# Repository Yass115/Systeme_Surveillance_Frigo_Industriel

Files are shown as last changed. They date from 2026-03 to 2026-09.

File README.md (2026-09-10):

# Système de surveillance d'un frigo industriel

Projet réalisé dans le cadre du cours **Conception et analyse de schémas** — ISIB, cours de M. Rodrigues.

## Objectif du projet

Concevoir une électronique de mesure et de surveillance destinée à être embarquée dans un frigo industriel, capable de détecter et signaler tout comportement anormal (porte oubliée, dérive de température, coupure de courant), depuis le schéma électronique jusqu'au circuit imprimé fini.

## Cahier des charges

| Exigence | Détail |
|---|---|
| Environnement | Boîtier étanche, tenue aux températures négatives |
| Mesure de température | Thermocouples, de préférence type T, connecteurs standards |
| Résolution | 1 °C ou mieux |
| Alerte à distance | En cas de comportement anormal (porte ouverte, baisse anormale de température, …) |
| Alerte locale | Alarme sonore/visuelle sur place |
| Communication | Ethernet |
| Consommation | Minimale |
| Alimentation | Protection contre les coupures de courant (secours sur batterie) |
| Indication | Témoins de fonctionnement (LEDs d'état) |

## Structure du projet

Le cours se déroule en deux volets complémentaires, correspondant aux deux dossiers du dépôt :

### 1. Schématique — `schematic/`
- Analyse du cahier des charges et découpage fonctionnel du système
- Choix et justification des composants (datasheets, calculs de dimensionnement)
- Câblage du schéma électronique complet
- Vérification des règles électriques (ERC)

### 2. Circuit imprimé — `pcb/`
- Placement des composants et contraintes mécaniques (boîtier, connecteurs)
- Routage des pistes (KiCad)
- Respect des règles de conception (largeur de piste, isolation, plan de masse)
- Génération des fichiers de fabrication (Gerbers, BOM, plan de perçage)

## Architecture électronique retenue

| Bloc | Composant | Rôle |
|---|---|---|
| Microcontrôleur | STM32L476 | Traitement, logique de surveillance |
| Mesure température (thermocouple) | MAX31855 + thermocouple type T | Mesure haute précision |
| Mesure température (secours/locale) | DS18B20 | Redondance de mesure |
| Communication | W5500 + MagJack RJ45 | Interface Ethernet |
| Alimentation secteur | HLK-PM01 (230 V → 5 V) | Alimentation principale isolée |
| Régulation | AMS1117-3.3 | Alimentation logique 3,3 V |
| Secours | Pile CR123A | Continuité de service en cas de coupure |

> La zone réseau 230 V est isolée de la basse tension par une barrière d'isolement, conformément aux règles de sécurité électrique.

## Outils utilisés

- **KiCad** — schématique et routage PCB
- **LaTeX** — rédaction du rapport de conception

## Organisation des fichiers

```
├── schematic/          # Fichiers de schéma KiCad, notes de choix de composants
├── pcb/                # Layout, règles de conception, fichiers de fabrication
├── datasheets/         # Documentation des composants clés
├── rapport/            # Rapport LaTeX du projet
└── README.md
```

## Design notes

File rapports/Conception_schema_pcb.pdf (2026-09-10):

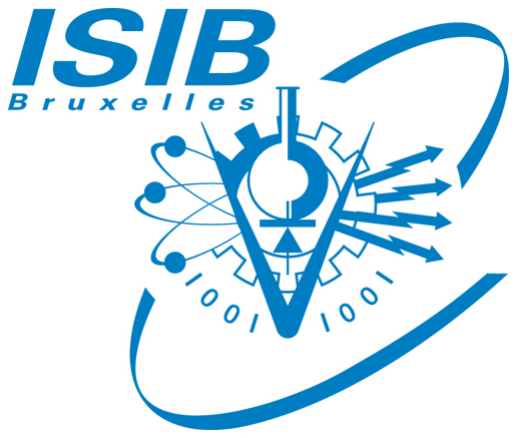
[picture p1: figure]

Institut Supérieur Industriel de Bruxelles

# Conception du circuit imprimé

## Système de surveillance d’un frigo industriel

Auteur : Yassine AMINE EL JAZAR

Professeur : M. Abilio Sergio RODRIGUES E SOUSA

Date : 2 septembre 2026

Rue des Goujons 28, 1070 Bruxelles (Belgique)

Conception du circuit imprimé

## Table des matières

1 Introduction | 1
2 Architecture à intégrer sur le PCB | 1
3 Contraintes de conception | 2
4 Technologie du circuit imprimé | 2
5 Zonage et placement des composants | 2
6 Isolement de la partie secteur | 5
7 Dimensionnement des pistes | 6
8 Routage des fonctions sensibles | 7
9 Étude thermique | 9
10 Règles mécaniques et assemblage | 9
11 Conclusion | 13
Références | 14

i

## 1 Introduction

Ce rapport est consacré à la conception du circuit imprimé du système de surveillance d’un frigo industriel. L’objectif n’est plus de comparer les composants possibles, mais de transformer l’architecture électronique retenue en une carte réalisable, sûre et fiable.
La carte doit mesurer la température au moyen d’un thermocouple de type T et d’un capteur DS18B20, traiter les données avec un microcontrôleur STM32L476, transmettre les informations par Ethernet et déclencher une alarme en cas d’anomalie. Elle doit également être alimentée depuis le secteur et continuer temporairement à fonctionner grâce à une pile de secours.
La conception du PCB doit donc répondre simultanément à plusieurs contraintes : présence du secteur 230 V, signaux de mesure de très faible amplitude, interface Ethernet, alimentation 3,3 V, fonctionnement dans un environnement froid et facilité de fabrication. Les règles présentées dans le document de cours Conception des circuits imprimés servent de base pour définir les largeurs de piste, les espacements, le plan de masse et les précautions thermiques.

## 2 Architecture à intégrer sur le PCB

Le schéma électrique est organisé autour des sous-ensembles présentés dans le tableau 1. Ces éléments constituent les données d’entrée de la conception du circuit imprimé.

Sous-ensemble | Composant principal | Fonction sur la carte
Traitement | STM32L476 | Acquisition des mesures, gestion des alarmes et communication avec les périphériques.
Mesure principale | MAX31855 + thermocouple T | Conversion du faible signal du thermocouple et transmission numérique par SPI.
Mesure ambiante | DS18B20 | Mesure numérique complémentaire par bus 1-Wire.
Communication | W5500 + Mag-Jack RJ45 | Gestion de la pile TCP/IP et liaison Ethernet vers l’extérieur du frigo.
Alimentation sec-teur | HLK-PM01 | Conversion isolée du 230 V alternatif vers 5 V continu.
Régulation | AMS1117-3.3 | Production du rail 3,3 V utilisé par les circuits nu-mériques.
Alimentation de secours | Pile CR123A | Maintien temporaire de la surveillance lors d’une coupure secteur.
Signalisation | LED, buzzer et relais éventuel | Indication de l’état du système et déclenchement d’une alarme locale.

Table 1 – Sous-ensembles à implanter sur le circuit imprimé

Le courant maximal estimé sur le rail 3,3 V est d’environ 174 mA. Cette valeur correspond au fonctionnement simultané du STM32L476, du W5500, du MAX31855 et des témoins du connecteur Ethernet. Elle sera utilisée pour dimensionner les pistes d’alimentation et la dissipation du régulateur.

## 3 Contraintes de conception

### 3.1 Contraintes électriques

La principale contrainte électrique est la présence de deux domaines de tension sur une même carte : le secteur 230 V et la basse tension 5 V/3,3 V. Ces domaines doivent être séparés par une barrière d’isolement sans piste, sans via et sans plan de cuivre.
Les autres contraintes électriques sont les suivantes :
— limiter la chute de tension dans les pistes d’alimentation ;
— fournir un retour de masse de faible impédance aux circuits numériques ;
— préserver l’intégrité des paires Ethernet et du signal d’horloge de 25 MHz ;
— éviter que les commutations du W5500, du buzzer ou du relais perturbent le thermocouple ; — assurer un découplage local de chaque circuit intégré.

### 3.2 Contraintes environnementales

La carte est destinée à fonctionner dans ou à proximité d’un environnement frigorifique. Le froid n’est pas l’unique difficulté : la condensation, l’humidité et les cycles thermiques peuvent également dégrader les contacts et le circuit imprimé. Le PCB doit donc recevoir un vernis épargne de bonne qualité et être installé dans un boîtier adapté. Un vernis de tropicalisation peut être ajouté après les essais, en protégeant préalablement les connecteurs, les boutons et les surfaces qui doivent rester accessibles.
Le MAX31855 doit être éloigné des composants qui chauffent afin de ne pas créer un gradient thermique autour de sa compensation de jonction froide. L’AMS1117 et le HLK-PM01 sont donc installés à distance de la chaîne de mesure.

## 4 Technologie du circuit imprimé

La face supérieure est utilisée pour les composants et la majorité des signaux. La face inférieure reçoit un plan de masse dans la zone basse tension, aussi continu que le permet le routage.
Le document de cours recommande de ne pas utiliser des pistes inférieures à environ 0,28 mm pour une réalisation standard. Une largeur minimale générale de 0,30 mm est donc adoptée. Cette valeur tient aussi compte de la morsure latérale, qui réduit légèrement la largeur réelle du cuivre pendant la gravure.

## 5 Zonage et placement des composants

Le placement est réalisé avant le routage. La carte est divisée en trois parties : une zone secteur, une zone d’isolement et une zone basse tension. Cette séparation réduit les risques électriques et évite que les pistes secteur traversent les circuits de mesure ou de communication.

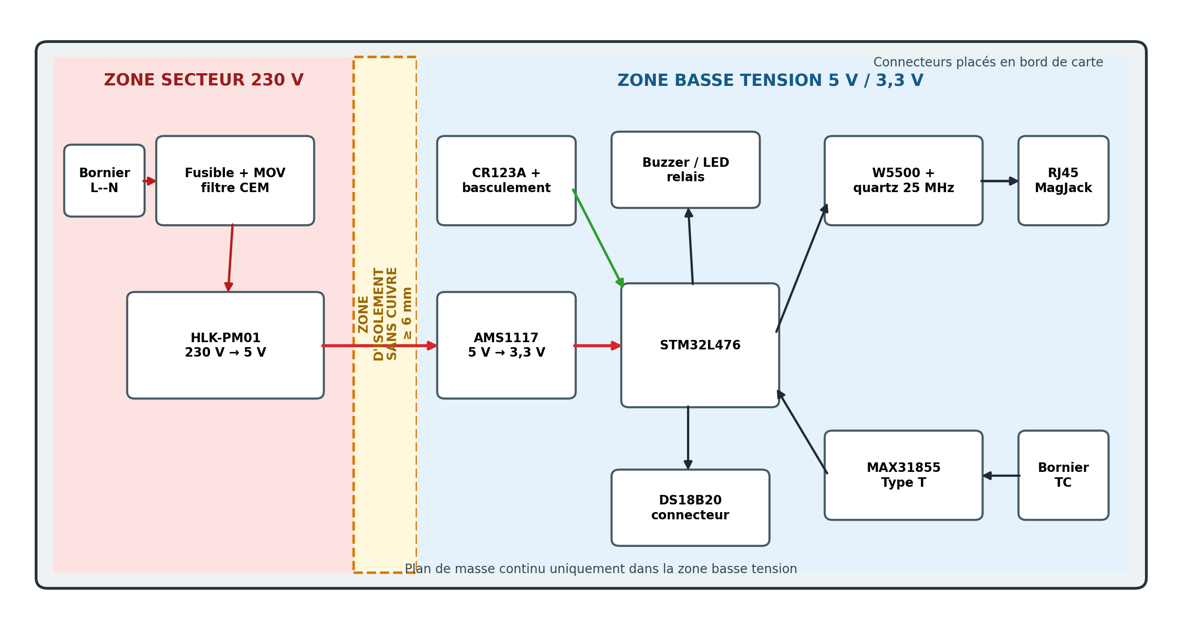
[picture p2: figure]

Figure 1 – Organisation fonctionnelle et séparation des différentes zones du PCB

Le bornier secteur, le fusible, la varistance, le filtre CEM et le HLK-PM01 sont regroupés sur un premier bord. Le STM32L476 est placé au centre de la partie basse tension afin de réduire la longueur moyenne des connexions. Le W5500 est rapproché du connecteur RJ45, tandis que le MAX31855 est rapproché du bornier du thermocouple.
La figure 2 présente une vue de principe de la face composants. Elle ne remplace pas le routage réalisé sous Eagle, mais elle fixe l’organisation spatiale à respecter lors de l’implantation définitive.

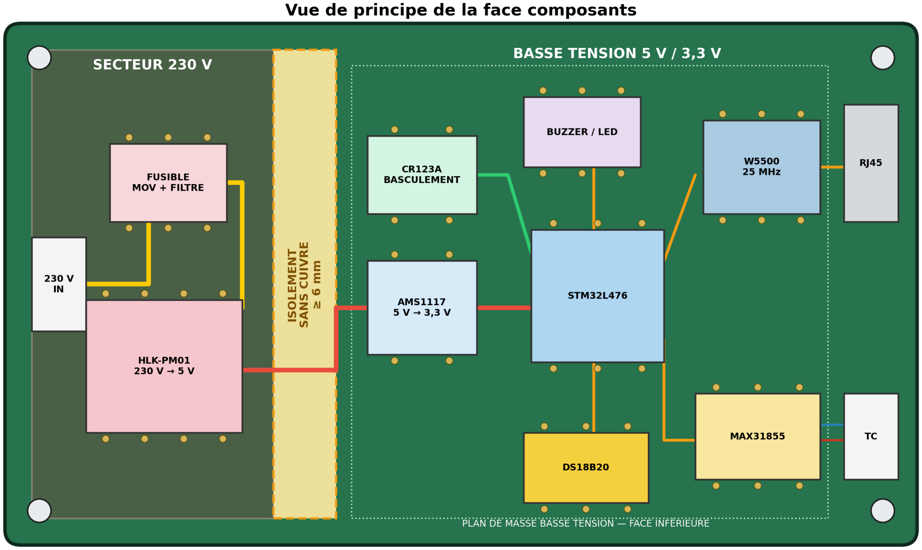
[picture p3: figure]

Figure 2 – Vue de principe de l’implantation sur la face composants

Les connecteurs sont placés sur le pourtour : entrée secteur, RJ45, thermocouple, DS18B20 et sorties d’alarme. Quatre trous de fixation sont prévus près des angles. Aucun composant haut ne doit gêner l’accès aux borniers ou au câble Ethernet.

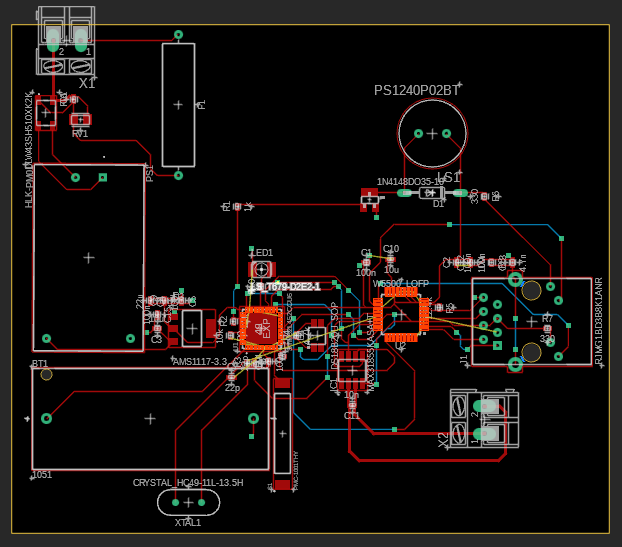
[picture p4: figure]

Figure 3 – Vue du PCB sous Eagle

L’implantation définitive s’écarte de la vue de principe de la figure 2. Certaines liaisons se sont révélées difficiles à router avec cette organisation, et les composants ont été réarrangés pour réduire la longueur des connexions critiques, notamment entre le W5500 et le MagJack et entre le bornier du thermocouple et le MAX31855. Le zonage secteur / isolement / basse tension est en revanche conservé.

## 6 Isolement de la partie secteur

L’espacement entre deux conducteurs doit augmenter avec la différence de potentiel. Un espacement insuffisant peut entraîner des courants de fuite, un amorçage électrique ou une dégradation progressive du substrat. Le graphique issu du document de cours illustre cette relation.

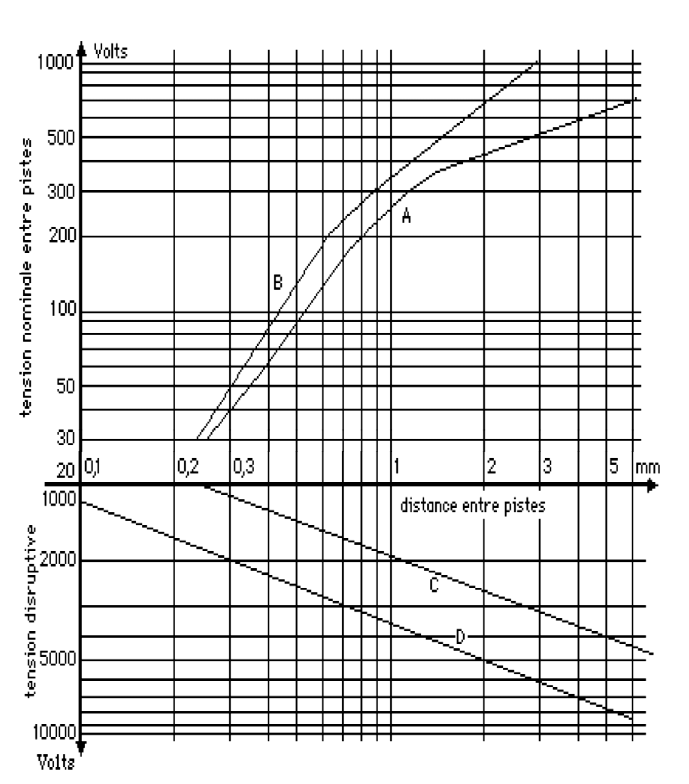
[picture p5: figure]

Figure 4 – Espacement entre pistes en fonction de la tension, extrait du document de cours fourni

Le réseau 230 V efficace correspond à une tension crête d’environ 325 V, pour laquelle le graphique conduit à un espacement de l’ordre de 1 à 1,5 mm. Les valeurs retenues ci-dessous sont volontairement supérieures, la condensation propre à un environnement frigorifique augmentant les courants de fuite en surface.
Pour le prototype, les règles suivantes sont appliquées :
— distance minimale de 3 mm entre la phase et le neutre ;
— distance minimale de 6 mm entre le cuivre relié au secteur et le cuivre basse tension, réalisée par une bande sans piste, sans via et sans plan de cuivre sur les deux faces.
Ces valeurs sont des règles conservatrices de conception pour le prototype. Une version destinée à une exploitation industrielle doit être vérifiée selon la norme applicable, la catégorie de surtension, le degré de pollution, le boîtier et les propriétés précises du matériau utilisé.

## 7 Dimensionnement des pistes

### 7.1 Influence de la largeur

La résistance d’une piste de cuivre de longueur L, de largeur w et d’épaisseur e est donnée par :

R = ρ

L
ew

(1)

où ρ représente la résistivité du cuivre. La puissance dissipée lorsque le courant I circule dans la piste vaut :
P = RI²
(2)

Une piste plus large diminue donc la résistance, la chute de tension et l’échauffement. Le graphique du cours présenté à la figure 5 donne l’ordre de grandeur de la largeur nécessaire pour du cuivre de 35 µm.

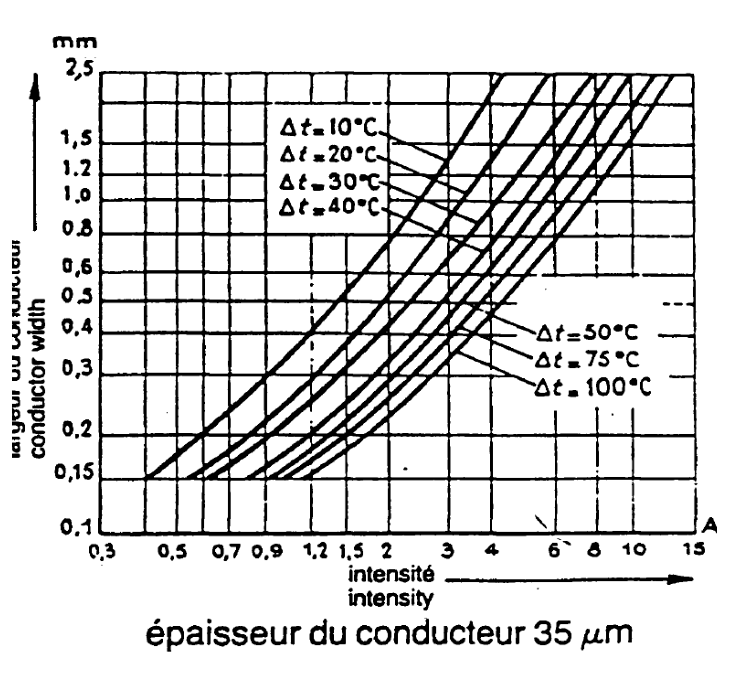
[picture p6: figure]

Figure 5 – Largeur de piste en fonction du courant pour du cuivre de 35 µm

### 7.2 Application au système

Le graphique du cours débute à 0,3 A. Le courant maximal du système, 0,174 A, se situe donc hors de la plage tracée, ce qui confirme que l’échauffement n’est pas le critère dimensionnant.

Liaison | Largeur | Justification
GPIO, 1-Wire et com-mandes | 0,30 mm | Courants faibles et compatibilité avec une fabrication standard.
Bus SPI | 0,30 mm | Priorité donnée à une faible longueur et à un plan de masse continu.
Distribution 3,3 V et 5 V | 0,50 mm mini-mum | Marge importante par rapport au courant maximal et réduction de la chute de tension.
Pile et départ d’ali-mentation | 0,80 mm mini-mum | Réduction de la résistance série lors des pointes de cou-rant du W5500.
Zone secteur | 1,00 mm mini-mum | Robustesse mécanique ; la sécurité est principalement as-surée par les espacements.
W5500 vers MagJack | 0,30 mm | Largeur et espacement constants sur toute la longueur ; paires courtes et appariées.

Table 2 – Largeurs de piste adoptées pour le routage

## 8 Routage des fonctions sensibles

Certaines fonctions imposent des contraintes plus strictes que les règles générales : la chaîne de mesure du thermocouple, la liaison Ethernet et la distribution d’alimentation. Elles sont traitées séparément ci-dessous. Aucun îlot de cuivre non connecté n’est laissé sur la carte : les zones isolées créées lors du remplissage des plans sont soit reliées à la masse, soit supprimées.

### 8.1 Alimentation et plan de masse

Les pistes d’alimentation suivent le chemin le plus court possible. La sortie 5 V du HLK-PM01 rejoint le circuit de basculement de la pile et l’entrée de l’AMS1117. La sortie 3,3 V est ensuite distribuée vers le STM32L476, le W5500, le MAX31855 et les autres charges.
Un condensateur de découplage est placé au plus près de chaque paire de broches d’alimentation. Des condensateurs réservoirs sont installés près de l’AMS1117 et du W5500 afin de fournir les pointes de courant. Les connexions entre les condensateurs et les broches doivent être courtes et larges.
Le cours rappelle qu’une piste présente toujours une inductance propre, de l’ordre de 10 nH/cm pour une largeur de 1 à 3 mm, particulièrement gênante sur les lignes d’alimentation des circuits à commutation rapide. Une liaison de 5 cm entre le régulateur et un circuit numérique représente ainsi environ 50 nH : lors d’une commutation provoquant une pointe de 50 mA en 10 ns, la chute de tension vaut U = L di/dt ≈ 0, 25 V, valeur non négligeable devant un rail de 3,3 V. C’est cette inductance, et non l’échauffement, qui justifie les largeurs retenues au tableau 2 ainsi que la réduction des longueurs. Le cours recommande également de faire cheminer l’aller et le retour du courant parallèlement et au plus près l’un de l’autre, afin que les champs créés par ces courants égaux et opposés s’annulent : c’est le rôle du plan de masse de la face inférieure, qui place le retour directement sous chaque piste d’alimentation.
La face inférieure reçoit un plan de masse sur toute la zone basse tension, interrompu à la frontière de la barrière d’isolement. Ce plan n’est pas parfaitement continu : quelques liaisons ont dû être routées sur la face inférieure et y créent des fentes locales. Celles-ci ont été écartées des retours de courant rapides (SPI, horloge 25 MHz, paires Ethernet), de manière que ces signaux conservent un chemin de retour direct sous leur piste. Les changements de couche ont été limités au strict nécessaire.

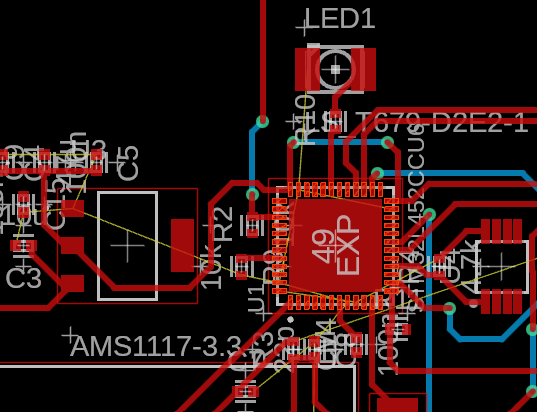
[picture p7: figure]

Figure 6 – Microcontrôleur

### 8.2 Thermocouple et MAX31855

Le thermocouple produit un signal de faible amplitude. Les deux pistes entre le bornier et le MAX31855 sont donc routées ensemble, courtes et sans via si possible. Elles sont éloignées du secteur, du quartz, du W5500, du buzzer et des pistes de puissance.
Le MAX31855 est placé dans une zone thermiquement homogène. Il ne doit pas se trouver près de l’AMS1117 ou du HLK-PM01, dont l’échauffement pourrait perturber la compensation de jonction froide. Le bornier est installé au bord de la carte pour éviter que les fils du thermocouple passent au-dessus des circuits numériques.

### 8.3 W5500 et Ethernet

Le W5500, son quartz de 25 MHz et le connecteur MagJack sont regroupés. Les pistes entre le quartz et le W5500 sont très courtes et symétriques. Les paires différentielles Ethernet sont routées avec une largeur et un espacement constants, des longueurs proches et le moins de vias possible.
Sur une carte double face, le plan de référence est éloigné des pistes de toute l’épaisseur du substrat : atteindre 100 Ω différentiel exigerait des pistes de plusieurs millimètres de large, incompatibles avec l’encombrement de la carte. L’impédance des paires n’est donc pas contrôlée. Ce choix reste acceptable pour une liaison 10/100 Mbit/s sur quelques centimètres, les longueurs en jeu étant très inférieures à la longueur d’onde des signaux. Les précautions portent donc sur la géométrie : paires courtes, largeur et espacement constants, couplage serré, longueurs appariées, aucun via et cuivre de masse continu sous les paires.

### 8.4 DS18B20 et alarmes

Le connecteur du DS18B20 est placé sur un bord. La résistance de rappel du bus 1-Wire est située près du microcontrôleur. Le buzzer et le relais éventuel sont placés près de leur étage de commande afin que leurs courants ne traversent pas la zone de mesure. Une diode de roue libre est installée directement aux bornes de la bobine si un relais électromécanique est utilisé.

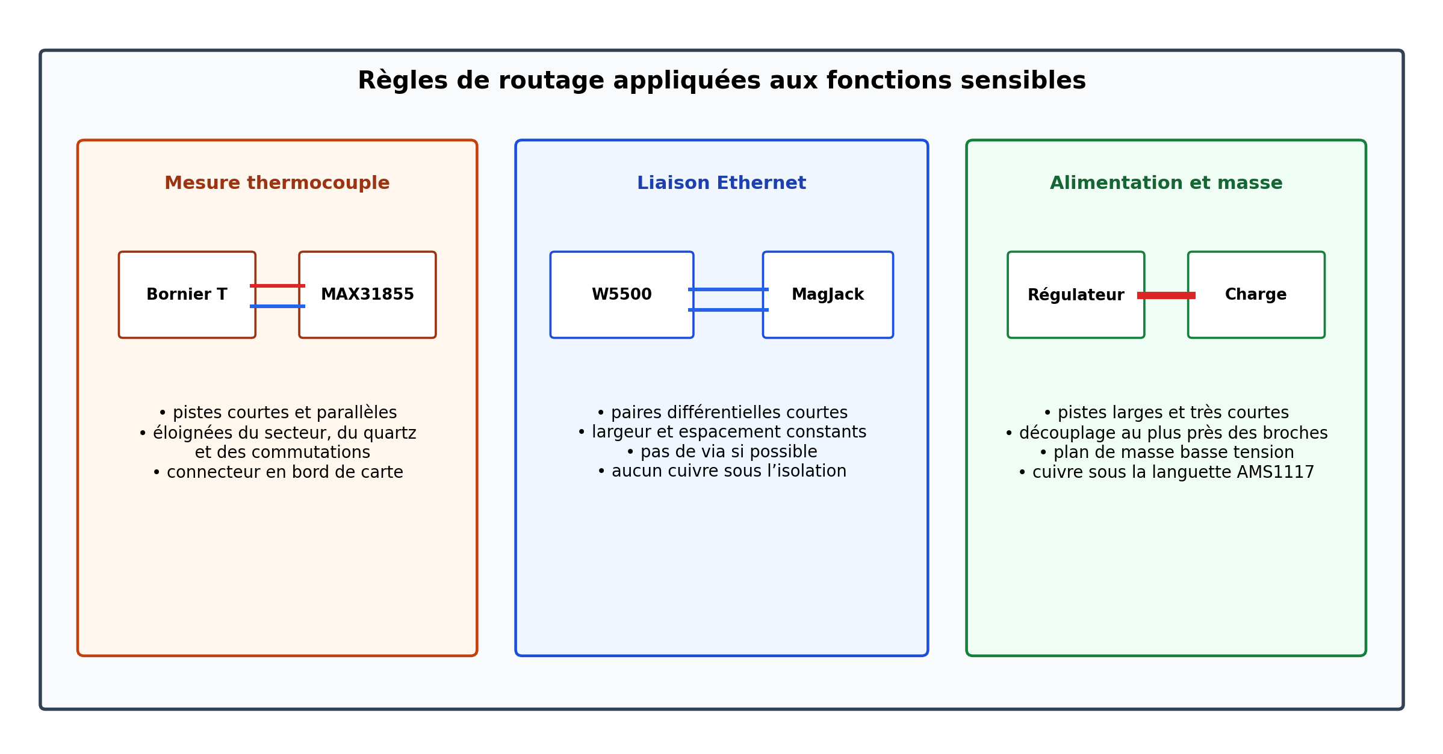
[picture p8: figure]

Figure 7 – Synthèse des règles appliquées aux fonctions sensibles

## 9 Étude thermique

L’AMS1117-3.3 abaisse la tension de 5 V à 3,3 V. Pour un courant maximal de 0,174 A, sa puissance dissipée est :

PD = (Vin − Vout)I = (5 − 3, 3) × 0, 174 = 0, 296 W | (3)

En prenant une résistance thermique jonction–ambiante d’environ 50 °C/W lorsque le boîtier SOT-223 dispose d’une surface de cuivre suffisante, l’élévation de température estimée est :
∆T = θJAPD = 50 × 0, 296 ≈ 15 °C | (4)

La languette du régulateur doit donc être reliée à une surface de cuivre assez large. Des vias thermiques peuvent relier les deux faces si nécessaire. Contrairement aux autres pastilles raccordées à un plan, cette languette ne doit pas être fortement isolée par des freins thermiques, car le cuivre participe à l’évacuation de la chaleur.
Le W5500 et le HLK-PM01 doivent également disposer d’un espace libre suffisant. Les composants sensibles à la température, notamment le MAX31855, sont placés hors de leurs zones d’échauffement.

## 10 Règles mécaniques et assemblage

Les composants lourds ou soumis à des efforts, comme les borniers, le RJ45 et le HLK-PM01, utilisent des pastilles traversantes suffisamment grandes. Pour les composants traversants, le diamètre extérieur de la pastille doit conserver une couronne de cuivre suffisante autour du trou après perçage.
Les recommandations mécaniques principales sont :

— placer quatre trous de fixation et maintenir le cuivre à distance de ceux-ci ; — laisser une marge entre les pistes et le bord du PCB ;
— orienter les borniers pour que les câbles sortent directement du boîtier ;
— utiliser des angles à 45° plutôt que des changements de direction aigus ;
— prévoir des freins thermiques sur les pastilles reliées aux grands plans ; — identifier les composants, polarités et connecteurs par sérigraphie ;
— signaler visuellement la zone secteur par un cadre et un avertissement ;
— strier les grands plans de cuivre.
Les grands plans de cuivre plein ont un coefficient de dilatation thermique très différent de celui du substrat isolant. Lors de la fabrication ou du passage au four de refusion, la chaleur provoque des contraintes mécaniques importantes dues à cette différence. Le plan strié permet de limiter ce problème : ses interstices agissent comme des joints de dilatation et réduisent considérablement les déformations du PCB.

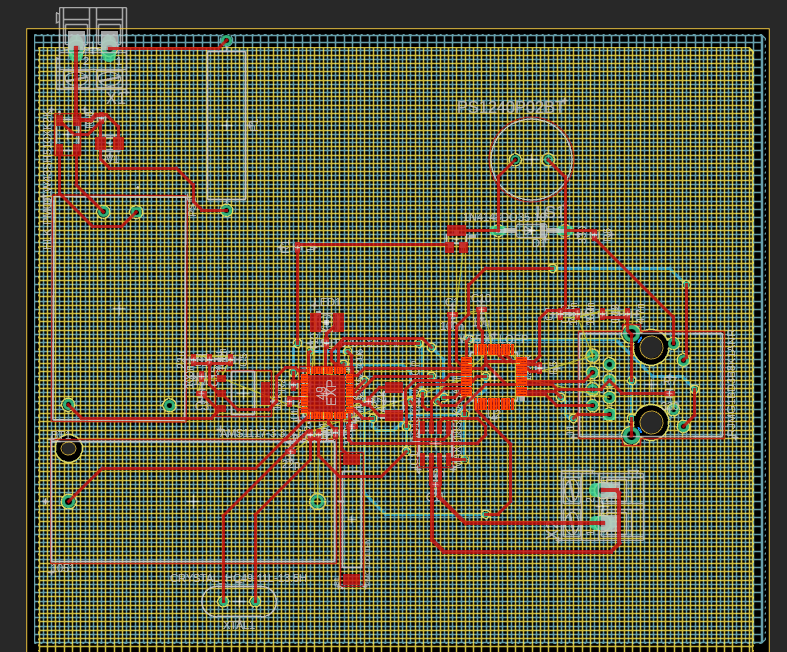
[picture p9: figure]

Figure 8 – Plans striés

Des points de test sont ajoutés sur 5 V, 3,3 V, GND, RESET, SWD, SPI et 1-Wire. Ils permettent de diagnostiquer la carte sans accéder directement aux broches fines des circuits intégrés.
Les angles droits sont évités lors du routage : à l’extérieur d’un angle vif, la largeur effective de la piste augmente localement, ce qui abaisse son impédance et introduit une capacité parasite réfléchissant une partie du signal. Sur les lignes rapides, notamment les paires Ethernet et le bus SPI, cette discontinuité dégrade les fronts de montée. Les changements de direction sont donc réalisés par deux angles à 45°.

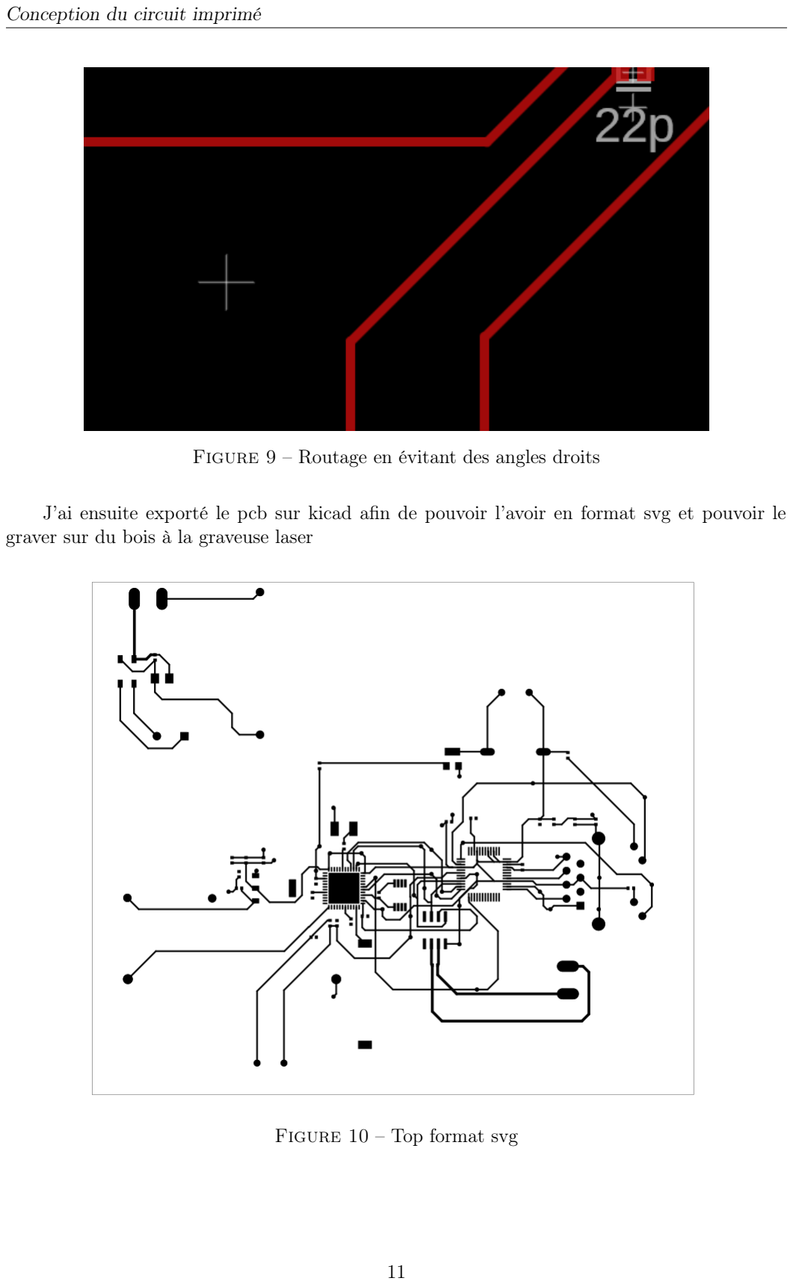
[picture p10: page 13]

Figure 9 – Routage en évitant des angles droits

J’ai ensuite exporté le pcb sur kicad afin de pouvoir l’avoir en format svg et pouvoir le graver sur du bois à la graveuse laser

Figure 10 – Top format svg

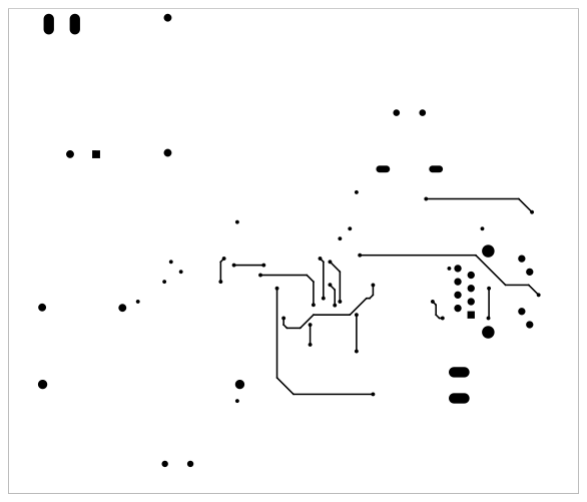
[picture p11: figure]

Figure 11 – Bottom format svg

## 11 Conclusion

Le circuit imprimé proposé regroupe sur une carte double face l’alimentation secteur, la régulation, le traitement, les capteurs, la communication Ethernet et les alarmes du système de surveillance frigorifique. La conception repose sur un zonage strict, une barrière d’isolement sans cuivre, un plan de masse strié réservé à la basse tension et des règles de routage adaptées à chaque fonction.
Les largeurs retenues sont volontairement supérieures au minimum thermique afin d’améliorer la robustesse et de limiter les chutes de tension. Le MAX31855 est protégé des sources de bruit et de chaleur, tandis que le W5500 est rapproché du MagJack pour garder des liaisons Ethernet courtes, à défaut d’une impédance contrôlée sur une carte double face. Les contrôles électriques, mécaniques et thermiques décrits dans ce rapport doivent être effectués avant la fabrication puis confirmés lors des essais du prototype.

## Références

— Document de cours : Conception des circuits imprimés
— Fiches techniques des composants STM32L476, W5500, MAX31855, DS18B20, HLK-PM01 et AMS1117-3.3.

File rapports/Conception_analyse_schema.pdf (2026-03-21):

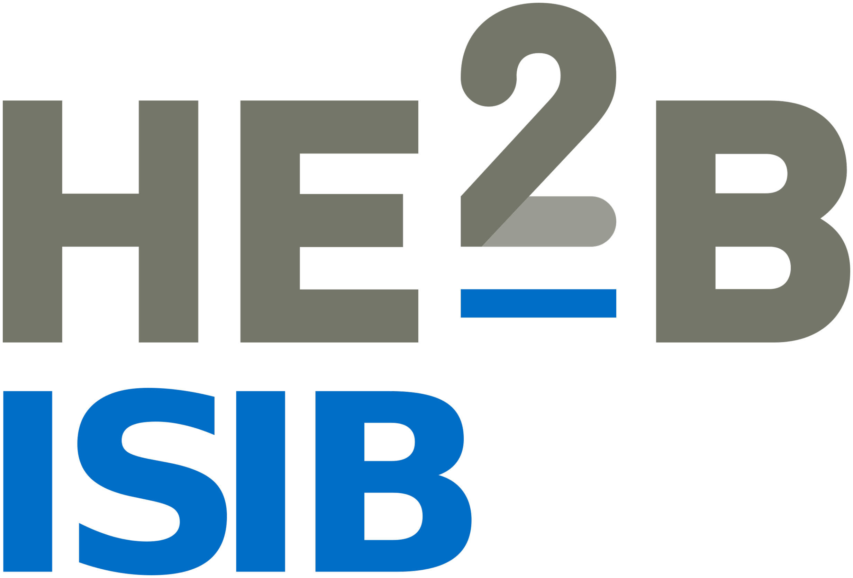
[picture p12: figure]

Institut Supérieur Industriel de Bruxelles

# Conception et analyse de schémas : Etude de conception d’un système de surveillance d’un frigo industriel

22 janvier 2026

Auteurs
Yassine AMINE EL JAZAR

Professeur
M. Abilio Sergio RODRIGUES E SOUSA

Rue des Goujons 28, 1070 Bruxelles (Belgique)

i

TABLE DES MATIÈRES

## Table des matières

1 Introduction | 1
2 Etude du cahier des charges | 1
3 Première proposition de système | 2
4 Etude de chaque élément du premier système | 3
5 Proposition finale | 9
6 Schéma du système elaboré sur fusion 360 | 10

i

2 ETUDE DU CAHIER DES CHARGES

## 1 Introduction

Dans le cadre de ce cours nous devons respecter un cahier des charges fourni par notre professeur pour la conception d’un système de surveillance d’un frigo industriel, pour chaque élement nous devrons fournir au moins trois solutions technologiques et en choisir une seule en justifiant notre choix (complexitée, cout, consommation,etc)

## 2 Etude du cahier des charges

Dans le cahier des charges il nous est précisé que l’électronique de mesure dont le dispositif sera constitué sera embarqué dans un boitier, capable de fonctionner dans un environnement avec des températures négatives. Il faudra donc pour chaque composant aller regarder sa Datasheet et etre sur de leurs capacité de fonctionnement dans des températures négatives. Les

avertissements en cas de comportements anormaux (porte oubliée, baisse anormale de température,etc) devront se faire à distance et il devrait aussi y avoir une alarme (buzzer ou sortie relais, en fonction de ce que l’on voudra mettre en place) pour signaler ça. Une communication par

Ethernet devra se faire entre le système et un ordinateur placé en dehors du frigo (car le frigo agis probablement comme une cage de Faraday) La consommation doit etre minimale (il fau-

dra bien inspecter les datasheets et comparer les differents composants possibles d’utilisation) La résolution doit etre d’au moins 1°C ou mieux, donc concrétemnt le systeme devra pouvoir

détecter quand on passe de 20°C à 21°C ou si on peut détecter (donc ici il faut comprendre que la résolution est la plus petite variation détectable) On devra aussi penser à un systeme de

backup électrique en cas de coupure de courant et ne pas oublier les témoins de fonctionnement (allumé/éteint, Ethernet(ok/pas ok))

3 PREMIÈRE PROPOSITION DE SYSTÈME

## 3 Première proposition de système

Juste après avoir lu le cahier des charges j’ai réalisé un schéma bloc (sans nom de composant précis) afin que je puisse avoir une vision globale du fonctionnement du système.

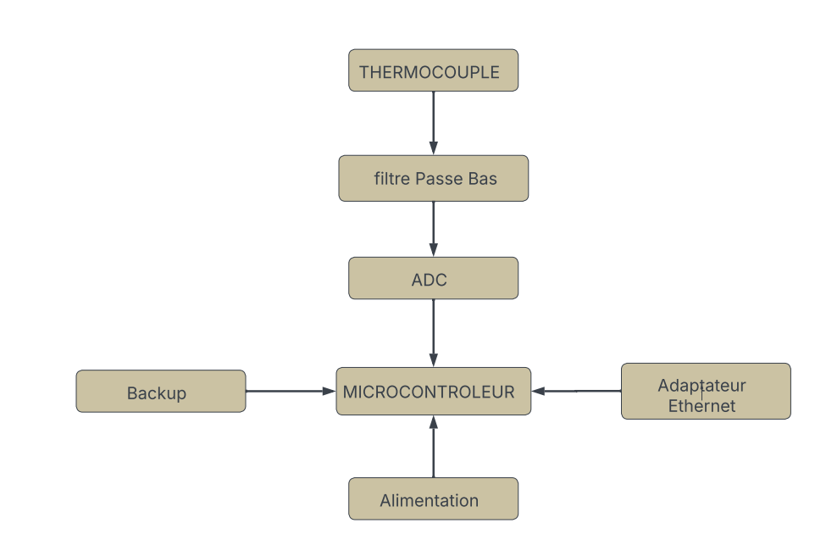
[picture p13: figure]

Figure 3.1 – Première proposition

Ici nous avons donc le thermocouple qui servira à prendre la mesure de la température et comme la température est une grandeur physique qui varie assez lentement j’ai pensé à placer un filtre passe bas afin d’essayer d’éliminer tout ce qui ne fait pas partie de la mesure qui nous intéresse.

La mesure de la température est une mesure analogique donc pour pouvoir utiliser ce signal avec un CPU nous devons le convertir en signal numérique, chose que nous ferons avec un convertisseur Analogique-Numérique (ADC), ici je place l’ADC à l’exterieur du microcontroleur car je ne sais pas encore quel microcontroleur je vais utiliser mais en fonction du microcontroleur il se pourrait que j’utilise l’ADC interne au microcontroleur s’il respecte le cahier des charges.

Nous avons aussi le bloc adaptateur Ethernet, il s’agit du bloc qui permettre de faire la jonction entre le microcontroleur et l’ordinateur situé à l’extérieur du frigo industriel, l’alimentation devra se faire directement sur secteur, donc nous devrons aussi penser l’adaptation 230V à 5V (microcontroleur). La partie backup servira en cas de coupure de courant imprévue pour que le système continue à fonctionner. Ici il ne faut pas oublier qu’il y a quelques élements du cahier decharge que je n’ai pas representé pour ne pas surcharger le schéma (comme les témoins d’état ou le système d’alarme)

4 ETUDE DE CHAQUE ÉLÉMENT DU PREMIER SYSTÈME

## 4 Etude de chaque élément du premier système

Dans cette section nous étudierons la possibilité d’utilisation des differentes technologies possibles et nous ferons aussi un choix en fonction des données mises àdisposition par les fabricants dans la datasheet de chaque composant.

### 4.1 Thermocouple

Un thermocouple est un capteur de température très courant, utilisé pour mesurer des températures dans des environnements très variés, souvent extrêmes (fours, moteurs, procédés industriels). Ici dans le cahier des charges on nous indique d’utiliser un thermocouple de type T (cuivre–constantan), ce qui parait plutot logique car nous voulons mesurer des températures froides, sa plage de température est de -200°C à +350°C.

### 4.2 Convertisseur Analogique-Numérique

En premier lieu j’ai pensé à utiliser un amplificateur (séparé de l’adc) par exemple utiliser l’AD8495 + ADC externe (L’AD8495 est un amplificateur spécialement conçu pour les thermocouples, fournissant une sortie analogique proportionnelle à la température mesurée. Cette solution abesoin de l’ajout d’un convertisseur analogique-numérique externe ainsi qu’un soin particulier dans le choix de la référence de tension et du filtrage).mais j’ai vite abandonné lidée après avoir trouvé des modules qui intègrent tout, cette solution m’aurait couté beaucoup plus de temps.

J’ai trouvé le MAX31855 qui est un convertisseur dédié aux thermocouples qui intègre l’ensemble de la chaîne de mesure : amplification du signal, compensation de jonction froide et conversion analogique-numérique. Il communique avec le microcontrôleur via une interface SPI, ce qui permet de transmettre directement une valeur numérique exploitable sans traitement analogique supplémentaire. Sa résolution de 0,25 °C est largement suffisante au regard du cahier des charges, qui impose une résolution d’au moins 1 °C. Cette intégration élevée permet de réduire le nombre de composants, d’améliorer la fiabilité du système et de simplifier le développement matériel et logiciel.

L’ADS1248 est un convertisseur analogique-numérique haute précision, intégrant des entrées différentielles, des amplificateurs programmables et une excellente résolution. Il est particulièrement adapté aux applications métrologiques ou nécessitant une très grande précision sur des signaux de faible amplitude, comme les ponts de mesure ou les capteurs résistifs de haute précision. Toutefois, dans le cadre de ce projet, ses performances dépassent largement les exigences du cahier des charges, qui ne requiert qu’une résolution de 1 °C. Son coût, sa complexité de mise en œuvre et son surdimensionnement en font une solution peu pertinente pour une application de surveillance thermique industrielle simple et fiable.

Pour finir j’ai bien choisi le MAX31855 car il est plus simple à intégrer, me permet d’avoir des composants en moins à gérer et il respecte très bien le cahier des charges.

### 4.3 Filtre passe-bas (anti-Aliasing)

Graçe à un bon choix du module ADC nous économisons un composant car le filtrage est intégré dans le module MAX31855.Pas besoin d’ajouter un module de filtrage.

### 4.4 Microcontroleur

Pour le microcontroleur j’ai tout de suite pensé à l’ESP32, il offre de la puissance de calcul et de la flexibilité mais c’est pas top en termes de consommation je l’ai donc comparé avec les autres options qui s’offraient à moi.

Il y a le STM32L476. Ce modèle est intéressant pour sa consommation dérisoire en veille (le mode Stop 2 est à 1,1 µA), permet de minimiser la consommation d’énergie quand le frigo est stable, prolongeant ainsi la durée de vie des composants et de la batterie de secours. On a aussi une broche VBAT dédiée : c’est elle qui garantit que l’horloge (RTC) continue de tourner via une pile bouton en cas de coupure de courant. C’est l’assurance que nos logs d’alertes seront toujours fiables.
Pour ce qui concerne les ressources, il possède 1 Mo de Flash et 128 Ko de RAM. Il gère sans souci le bus SPI pour le MAX31855 et le contrôleur Ethernet, en plus des timers pour les alarmes. Petit bonus non négligeable : il est certifié pour descendre jusqu’à -40°C, donc aucun problème vis-à-vis des contraintes environnementales du projet.
Pour ce qui est des inconvenients il y en a 4 principaux, il ne possède pas de port Ethernet natif complet (PHY intégré) donc je devrais ajouter un W5500 ce qui augmente légèrement le nombre de composants sur le schéma. La compléxité pour la mise en oeuvre par rapport à un ESP32 ou à un PIC et son prix unitaire. La tension d’alimentation doit aussi etre bien gérée car on doit l’alimenter à 3,3V alors qu’on adapte 230v en 5v donc il faut réguler la tension.

Le Microchip PIC18F97J60 est l’un des rares microcontrôleurs à intégrer à la fois le MAC (le cerveau de la communication) et le PHY (la couche physique, le signal électrique) Ethernet dans la même puce. C’est donc une solution intéressante car on élimine le besoin de puces de communication supplémentaires, ce PIC18F97J60 possède aussi un grand nombre de pins (100) sur lesquels on peut facilement venir mettre tout les circuits dont nous avons besoin (alarmes, temoins,etc). Autre avantage, puisque le PHY est intégré, les pistes à haute fréquence (signaux Ethernet) sortent directement du microcontrôleur vers le connecteur RJ4 et celà rends le design du circuit plus robuste face aux interférences électromagnétiques. Malgré ces avantages il existe des inconvenients non négligeables.
La mémoire RAM et Flash est souvent plus restreinte. Si vous décidez plus tard d’ajouter une interface web de configuration ou un envoi d’emails sécurisés, vous risquez de manquer de ressources (mémoire saturée).
Voici un tableau comparatif qui reprends tout ce que j’ai énnoncé :

Table 4.1 – Comparaison des microcontrôleurs pour le système de surveillance de frigo industriel

Critère | Microchip PIC18F97J60 | Espressif ESP32-WROOM | ST STM32L476RG
Prix approx. | ∼ 5 - 7 € | ∼ 3 - 5 € | ∼ 7 - 10 €
Consommation | Élevée (∼50mA en actif) | Moyenne (∼80-240mA actif) | Minimale (100µA/MHz)
Tension (Vcc) | 3.3V (non tolérant 5V) | 3.3V (non tolérant 5V) | 3.3V (broches tolérantes 5V)
Mémoire RAM | 3.8 Ko (Très limitée) | 520 Ko (Très élevée) | 128 Ko (Confortable)
Mémoire Flash | 128 Ko (Limitée) | 4 Mo (Très élevée) | 1 Mo (Confortable)
Flexibilité | Faible (Architecture 8-bit) | Élevée (Double cœur, WiFi/BT) | Élevée (Périphériques ind.)
Évolutivité | Nulle (Saturation mémoire) | Excellente (Serveur Web) | Excellente
Ethernet | Natif (MAC+PHY) | MAC intégré (besoin PHY) | Besoin module externe (SPI)

### 4.5 Ethernet

Pour la communication ethernet il nous faudra un controleur ethernet (il gère la transmission et la réception des données, il transforme les données numériques en trames pretes à etre envoyées et s’assure qu’l n’y ai pas de collision).

On a le controleur LAN8720A qui n’est pas cher et est beaucoup plus rapide que le SPI mais est gourmand en RAM, le STM32 doit faire tourner la pile logicielle et donc consomme une grande partie des 128 ko de RAM. En terme de mise en oeuvre il nécessite entre 7 et 9 connexions (liaison RMII (Reduced Media Independent Interface), il s’agit d’une interface standard utilisée pour connecter le contrôleur Ethernet (MAC) au transmetteur physique (PHY)) et une horloge de 50MHz qui doit etre stable.

Il existe des solutions plug and play comme le ENC28J60 (via SPI), en termes de cout il est très bon marché et est très documenté mais il consomme énormément (150mA - 200mA) et gère mal les collisions donc il ne sera pas choisi.

Ensuite nous avons le Wiznet W5500 (via SPI), c’est un processeur réseau qui gère tout seul la pile TCP/IP doncla charge sera bien allégé pour le STM32. Il possède un mode "Power Down", il permet de désactiver la couche physique qui est la partie la plus gourmande en energie. L’un des inconvenients de ce module est le débit qui est limité par la vitesse du bus SPI (suffisant pour du transfert de données de température mais pas pour de la vidéo par exemple).J’ai du rajouter un quartz de 25 MHz avec lesquels j’ai mis des condensateurs de charge qui aident au démarrage et à la stabilité de l’oscillation, puis j’ai ajouté une resistance de feedback (qui va forcer l’amplificateur present dans le W5500 à fonctionner dans sa zone linéaire au démarrage).
Voici un tableau récapitulatif pour le controleur Ethernet :

Table 4.2 – Comparaison des solutions Ethernet pour STM32L4 (Consommation à 3.3V)

Modèle | Mode Actif (Typ.) | Mode Low-Power | Impact CPU
Wiznet W5500 | 132 mA | 0.02 mA (PDn) | Pas d’impact significatif
LAN8720A | ∼45 mA | ∼2 mA (S-down) | Élevé
ENC28J60 | 160 - 180 mA | ∼2 µA | Très Élevé

Bien qu’en terme de consommation le LAN8720A semble avantageux en réalité il ferait travailler le STM32 de manière intensive pour gérer la pile logicielle contrairement au W5500 qui la gère lui meme.Pour ce qui est du ENC28J60 sa consommation dépasse souvent les 160 mA en fonctionnement normal et il demande énormément de ressources au microcontrôleur pour simplement maintenir une connexion. À exclure pour une installation dans un frigo industriel où la fiabilité et l’énergie sont critiques.Avec le controleur j’ai ajouté un port RJ45 afin de pouvoir établir une connexion direct, j’ai choisi le RJMG1BD3B8K1ANR car contrairement à un simple port rj45 ce connecteur intègre des transformateurs d’isolement et des bobines d’arret (chokes) donc concrètement il protège contre les décharges statiques et les pics de tension sur le cable réseau et réduit les intérferences électromagnétiques (ce dernier point est essentiel dans un milieu frigorifique ou les démarrages de compresseur générent beaucoup de bruit parasite). Il possède aussi des temoins de fonctionnement intégrès (led verte et jaune).

### 4.6 Système de Backup

Plusieurs systèmes sont possibles pour prévenir une coupure de courant. L’une des premières idées qui m’est venue en tete c’est l’utilisation d’une batterie qui fonctionnerait à des températures négatives (comme par exemple la pile Lithium primaire CR123A) elle n’est pas rechargeable ce qui simplifie le schema électronique mais à un cout de maintenance (changement de la pile après chaque décharge profonde sinon elle peut tenir entre 2 et 3 ans).

On peut utiliser une batterie rechargeable comme la Saft MP xtd, l’un des avantages de cette batterie est qu’elle se recharge toute seule quand le secteur revient (meme à -20 C°) sa durée de vie est plus longue que la solution précedente par contre elle est plus chère et nécessite un circuit de recharge spécifique capable de gerer les sondes de température pour sécuriser la charge donc plus complexe à mettre en place.

Il y a aussi les supercondensateurs, ils stockent l’energie de manière électrostatique plutot que chimique, supportent des millions de cycles de charges/décharges sans s’user, ils sont insensibles au froid et n’ont aucun risque de fuite ou d’incendie par contre l’autonomie est très courte (quelques minutes, suffisant pour envoyer une alerte et sauvegarder les données mais ne permet pas de monitorer pendant des heures.

Il me parait plus judicieux d’utiliser la CR123A car à une bonne autonomie et permet au W5500 de consomer ses 132mA lors de la transmission d’alerte sans s’effondrer tout en restant simple à integrer

### 4.7 Alimentation

Pour ce qui est de l’alimenation j’ai pu étudier plusieurs stratégies possibles, il y a le PoE (Power over Ethernet) mais pour l’utiliser il me faut des transformateurs spécifiques et un routage très strict pour respecter ls distances d’isolement. Les modules d’extraction (PD) et ces transformateurs prennent plus de place sur un PCB, les convertisseurs DC/DC utilisées dans le PoE découpent la tension à haute fréquence, ce qui peut créer des parasites sur les mesures analogiques.
J’ai donc opté pour une alimentation sur secteur car cela permettra de ne pas etre limité en terme d’energie, il faut donc que je puisse passer de 230V à 5V, pour celà nous pourrons utiliser le HLK-PM01 qui est un module d’alimentation compact à découpage (AC-DC) de type step down mais il faut mettre en place les protections qui s’imposent, j’ai donc mis un fusible sur la phase pour prévenir les surintensités et une varistance (il s’agit d’une resistance qui varie de manière non-linéaire en fonction de la tension) sa valeur est très grande en temps normal mais quand il y a un pic de tension alors sa valeur devient très faible ce qui permet de court circuiter le circuit et rediriger l’energie vers l’exterieur pour ne pas endomager les composants, ensuite j’ai ajouté un condensateur afin de pouvoir nettoyer les parasites hautes frequences qui circulent sur le reseau électrique et en dernier lieu il y a l’inductance de mode commun elle empeche les bruits liés à la commutation, sans cette inductance mon MCU pourrait avoir des valeurs erronés ou redemarrer sans raison à cause du bruit électrique.
Ensuite voici quel serait la consomation maximale en mA du système :
Composant | Consommation Max (mA) | État / Mode
STM32L452 | 30 | Mode Run @ 80MHz
W5500 | 132 | Transfert Ethernet
MAX31855 | 1.5 | Conversion active
LEDs (RJ45) | 10 | Link + Activity
Total | 173.5 mA | Pleine charge

Table 4.3 – Bilan des puissances sur le rail 3.3V

J’ai donc comparé 3 régulateurs differents en prenant e compte aussi la dissipation thermique (qui est un facteur important dans le cadre de notre application) :

Caractéristique | AMS1117-3.3 | 78L33 | MCP1700
Courant Max | 800 mA | 100 mA | 250 mA
Tension de déchet | 1.1 V | 1.7 V | 0.17 V
Boîtier | SOT-223 | TO-92 | SOT-23
Dissipation Thermique | Bonne | Mauvaise | Faible
Verdict | Choisi | Insuffisant | Risqué

Table 4.4 – Comparaison des solutions de régulation 5V vers 3.3V

Le régulateur de tension linéaire (AMS1117-3.3) dissipe l’excédent de puissance sous forme de chaleur par effet Joule. Il est donc important de vérifier que la puissance dissipée (PD) ne conduit pas à un dépassement de la température de jonction admissible du composant.
Les paramètres de calcul sont les suivants :
— Tension d’entrée (Vin) : 5 V (issue du module HLK-PM01).
— Tension de sortie (Vout) : 3, 3 V (alimentation du système).
— Courant de sortie estimé (Iout) : 0, 174 A.
La puissance dissipée est calculée selon la formule suivante :
PD = (Vin − Vout) × Iout | (4.1)

En appliquant les valeurs de notre conception :

PD = (5 V − 3, 3 V) × 0, 174 A = 0, 2958 W | (4.2)

L’augmentation de température de la jonction du régulateur par rapport à l’air ambiant est donée par la loi d’Ohm thermique. Elle dépend de la puissance dissipée et de la capacité du boîtier à évacuer cette chaleur.
Pour le boîtier SOT-223 de l’AMS1117, la résistance thermique jonction-ambiant (θJA) est le paramètre clé. En prévoyant une surface de cuivre minimale sur le PCB (plan de masse), on retient la valeur typique suivante (dans la datasheet) :
θJA ≈ 50 °C/W | (4.3)

### 2. Calcul de l’élévation de température (∆T)

L’élévation de température (∆T) est le produit de la puissance dissipée (PD) par la résistance thermique du boîtier :
∆T = θJA × PD | (4.4)

En utilisant la puissance dissipée calculée précédemment (PD ≈ 0, 3 W) :

∆T = 50 °C/W × 0, 3 W = 15 °C | (4.5)

Analyse : Avec une puissance à dissiper d’environ 0, 3 W, le boîtier SOT-223 de l’AMS1117 présente une résistance thermique jonction-ambiant (θJA) suffisante pour limiter l’échauffement. L’augmentation de température estimée est d’environ +15 °C par rapport à la température ambiante. Le composant restera donc parfaitement fiable, même dans des conditions de fonctionnement sévères, respectant ainsi les exigences de robustesse du cahier des charges. L’un des risques est le cold start mais le choix de l’AMS1117 est judicieux car il est conçu pour démarrer même avec une tension de déchet (dropout) qui augmente légèrement avec le froid.

### 4.8 Mesure de la temperature ambiante

Il nous faudrait aussi un capteur de temperature afin de pouvoir mesurer la temperature ambiante de la piece et ainsi relever les variations anormales et les signaler si nécessaire.

Critère | DS18B20 | Thermocouple K | NTC (Thermistance)
Type de sortie | Numérique (1-Wire) | Analogique (µV) | Analogique (Ω)
Plage type | −55°C à +125°C | −200°C à +1300°C | −40°C à +125°C
Précision | ±0, 5°C (Haute) | ±1°C à 2°C (Moyenne) | Faible (Non-linéaire)
Interface | Directe (1 GPIO) | Nécessite MAX31855 | Pont diviseur + CAN
Coût système | Faible | Élevé (Capteur + CI) | Très faible

Table 4.5 – Comparatif des solutions de mesure de température pour environnement industriel

L’un des points fort de Le DS18B20 est la transmission numérique. Contrairement à une NTC, le signal ne se dégrade pas si le câble fait 10 mètres de long. La valeur lue par le STM32 est exactement celle mesurée. L’économie d’énergie . Il consomme presque rien en mode repos et n’utilise qu’une seule broche du microcontrôleur.En utilisant un capteur numérique (DS18B20) et un capteur analogique numérisé par puce dédiée (Thermocouple + MAX), on évite qu’un même défaut (parasite sur le bus SPI ou erreur logicielle sur le 1-Wire) ne bloque toute la surveillance du frigo (redondance).

5 PROPOSITION FINALE

## 5 Proposition finale

Dans cette section je mets juste mon schéma bloc mais avec les composants choisis, les modifications apportés et les differentes relations entre ces blocs (les fleches rouge c’est pour de l’alimentation, les fleches noir indiquent leflux des données et la fleche verte c’est l’alimentation en cas de coupure).

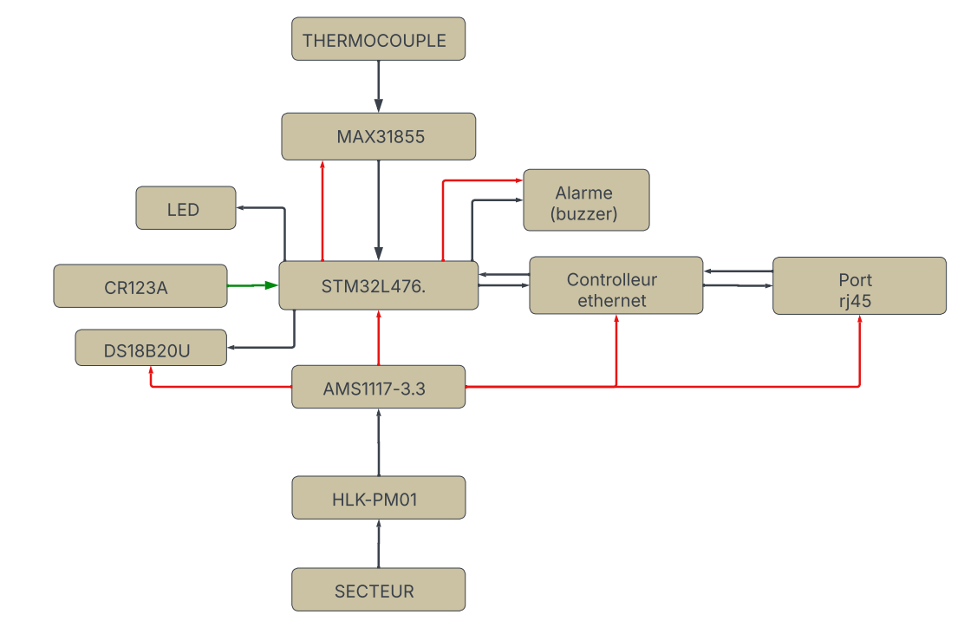
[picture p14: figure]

Figure 5.1 – Schema bloc modifié

Ce système respecte bien le cahier des charges, le choix des composants a été réflechie et guidé par le cahier des charges tout en essayant d’optimiser certains critères (comme la consommation).

## 6 Schéma du système elaboré sur fusion 360

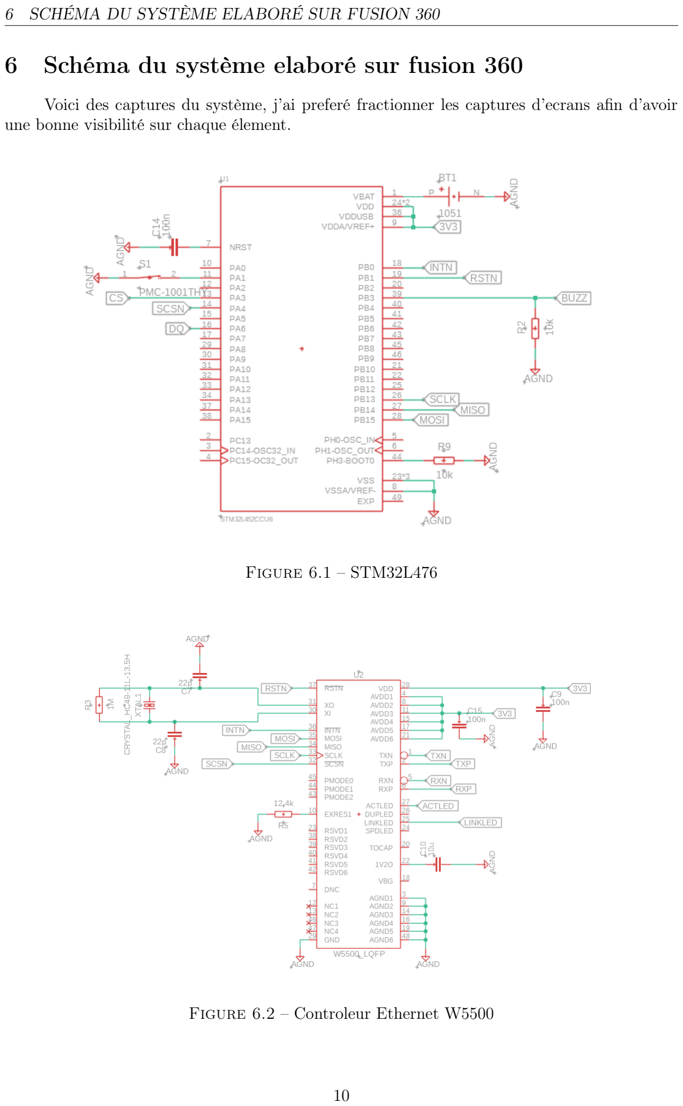
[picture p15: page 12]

6 SCHÉMA DU SYSTÈME ELABORÉ SUR FUSION 360

Voici des captures du système, j’ai preferé fractionner les captures d’ecrans afin d’avoir une bonne visibilité sur chaque élement.

Figure 6.1 – STM32L476

Figure 6.2 – Controleur Ethernet W5500

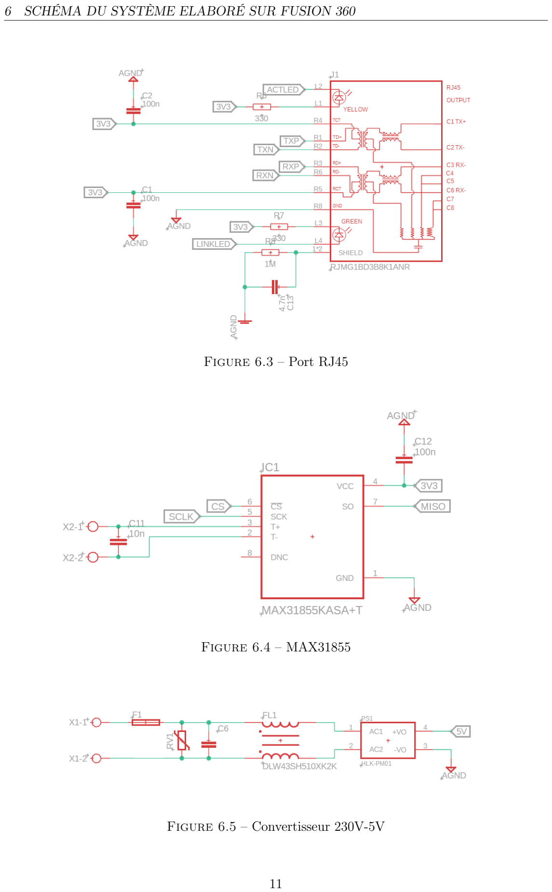
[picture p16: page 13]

6 SCHÉMA DU SYSTÈME ELABORÉ SUR FUSION 360

Figure 6.3 – Port RJ45

Figure 6.4 – MAX31855

Figure 6.5 – Convertisseur 230V-5V

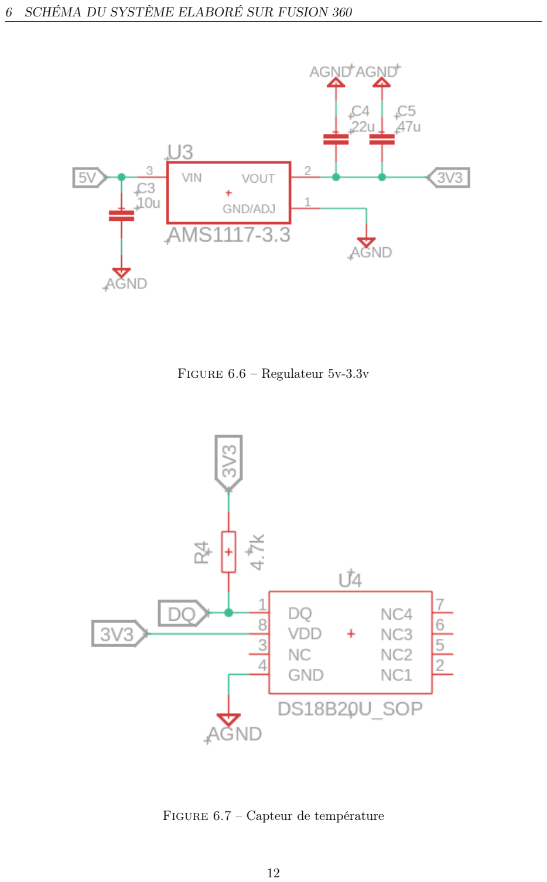
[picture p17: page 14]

6 SCHÉMA DU SYSTÈME ELABORÉ SUR FUSION 360

Figure 6.6 – Regulateur 5v-3.3v

Figure 6.7 – Capteur de température

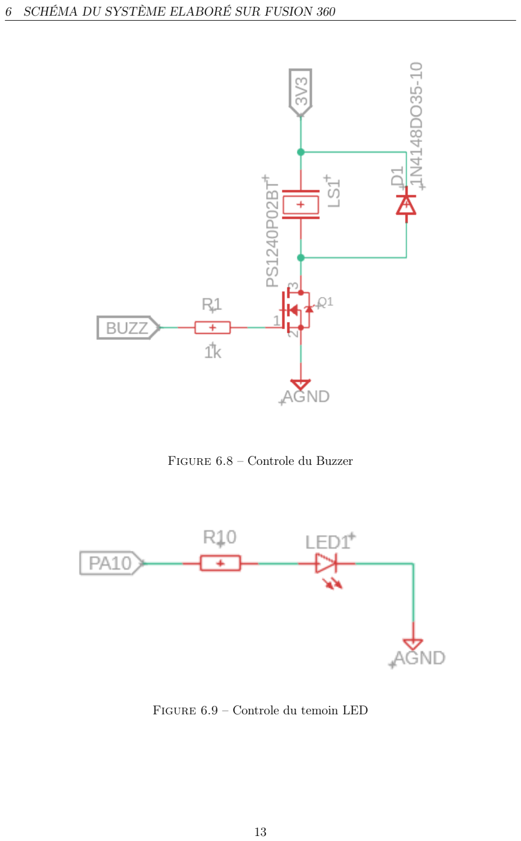
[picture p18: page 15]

6 SCHÉMA DU SYSTÈME ELABORÉ SUR FUSION 360

Figure 6.8 – Controle du Buzzer

Figure 6.9 – Controle du temoin LED

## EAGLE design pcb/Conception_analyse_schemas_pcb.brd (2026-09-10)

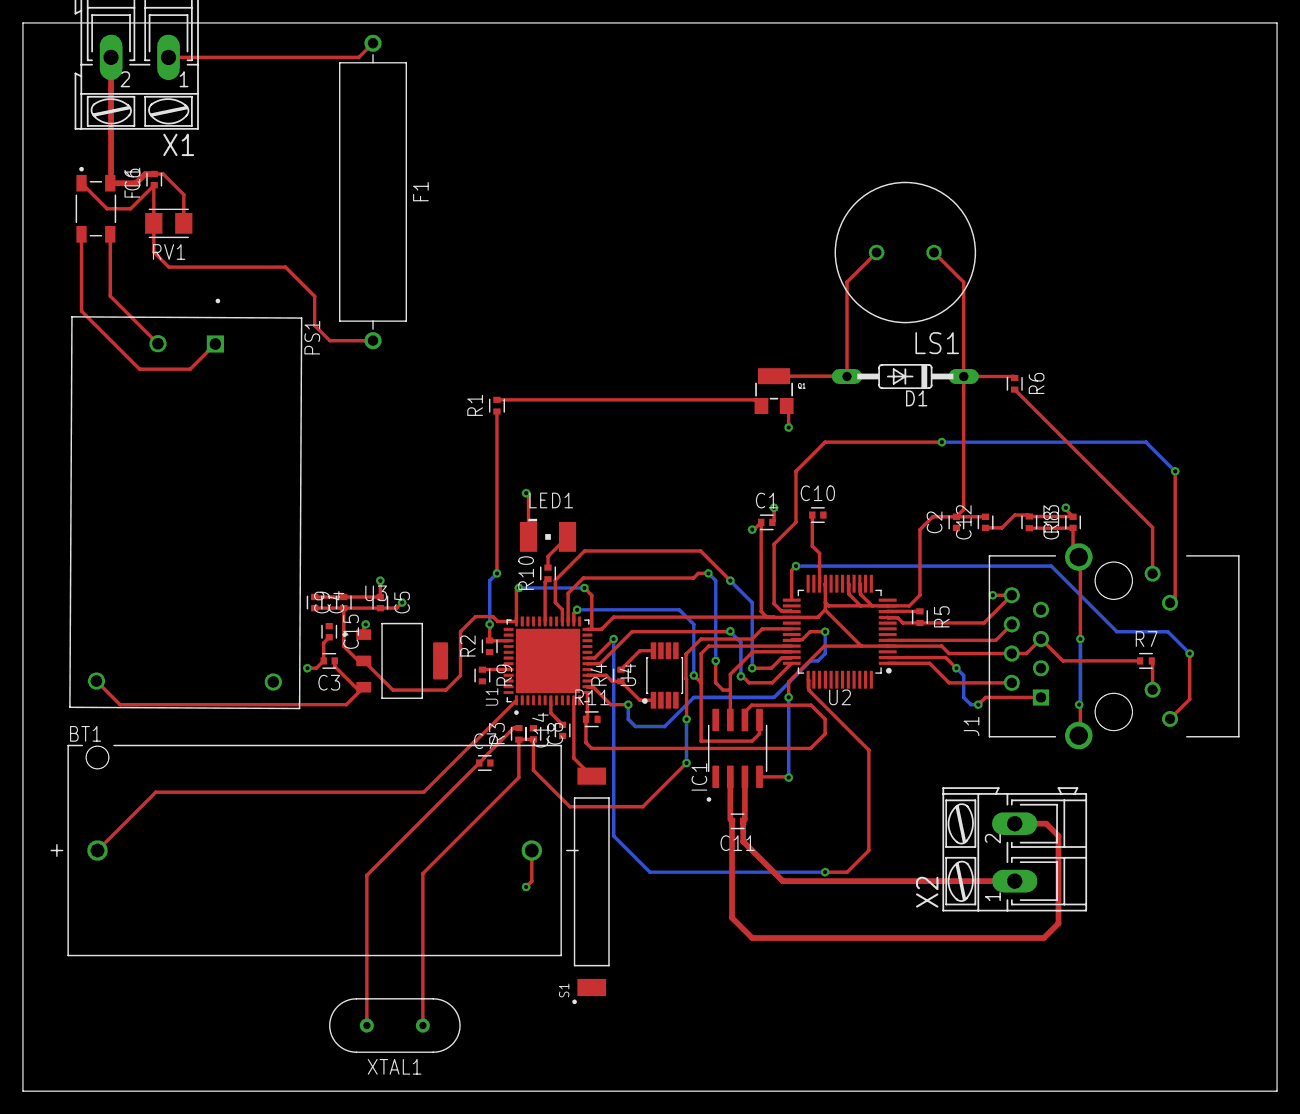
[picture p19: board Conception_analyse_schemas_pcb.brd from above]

Board: 4 copper layers, 109.2 x 93.0 mm, 45 parts (0 on the bottom side), 41 nets.

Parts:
BT1: 1051; BAT_1051
C1, C2, C9, C12, C14, C15: 100n; CAPC1005X60
C3, C10: 10u; CAPC1005X60
C4: 22u; CAPC1005X60
C5: 47u; CAPC1005X60
C6: CAPC1005X60
C7, C8: 22p; CAPC1005X60
C11: 10n; CAPC1005X60
C13: 4.7n; CAPC1005X60
D1: 1N4148DO35-10; DO35-10
F1: FUSAD2590W70L2150D550B
FL1: DLW43SH510XK2K; FIL_DLW43SH510XK2K
IC1: MAX31855KASA+T; SOIC127P600X175-8N
J1: RJMG1BD3B8K1ANR; CONN_RJMG1BD3B8K1ANR
LED1: LS_T679-D2E2-1; PLCC2
LS1: PS1240P02BT; XDCR_PS1240P02BT
PS1: HLK-PM01; CONV_HLK-PM01
Q1: SOT23-W
R1: 1k; RESC1005X40
R2, R9: 10k; RESC1005X40
R3, R8: 1M; RESC1005X40
R4: 4.7k; RESC1005X40
R5: 12.4k; RESC1005X40
R6, R7: 330; RESC1005X40
R10, R11: RESC1005X40
RV1: VARC3216X102N
S1: PMC-1001THY; SW_PMC-1001THY
U1: STM32L452CCU6; QFN50P700X700X60-49N
U2: W5500_LQFP; QFP50P900X900X160-48N
U3: AMS1117-3.3; SOT229P700X180-4N
U4: DS18B20U_SOP; SOP65P491X110-8N
X1, X2: AK300/2
XTAL1: CRYSTAL_HC49-11L-13.5H; XTALRR488W43L1135T465H1346B

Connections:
3V3: C1.1, C2.2, C4.2, C5.2, C9.1, C12.2, D1.C, IC1.4, J1.R4, J1.R5, LS1.1, R6.1, R7.1, U1.24, U1.36, U2.4, U2.8, U2.11, U2.15, U2.17, U2.21, U2.28, U3.2
5V: C3.1, PS1.4, U3.3
ACTLED: J1.L2, U2.27
AGND: BT1.N, C1.2, C2.1, C3.2, C4.1, C5.1, C7.2, C8.1, C9.2, C10.2, C12.1, C13.2, C15.2, J1.R8, LED1.C, Q1.2, R5.2, R8.1, R9.2, U1.8, U1.23, U1.35, U1.47, U2.3, U2.9, U2.14, U2.16, U2.19, U2.29, U2.48, U3.1
BUZZ: R1.1, R2.2, U1.39
CS: IC1.6, R11.1, U1.13
DQ: R4.1, U1.16, U4.1
INTN: U1.18, U2.36
LINKLED: J1.L4, U2.25
MISO: IC1.7, U1.27, U2.34
MOSI: U1.28, U2.35
unnamed: Q1.1, R1.2
unnamed: F1.1, X1.1
unnamed: D1.A, LS1.2, Q1.3
unnamed: C6.1, F1.2, FL1.1, RV1.2
unnamed: C6.2, FL1.4, RV1.1, X1.2
unnamed: FL1.3, PS1.2
unnamed: FL1.2, PS1.1
unnamed: C7.1, R3.2, U2.31, XTAL1.2
unnamed: C8.2, R3.1, U2.30, XTAL1.1
unnamed: C10.1, U2.22
unnamed: S1.2, U1.11
unnamed: C11.1, IC1.3, X2.1
unnamed: BT1.P, U1.1
unnamed: R5.1, U2.10
unnamed: C11.2, IC1.2, X2.2
unnamed: J1.L1, R6.2
unnamed: J1.L3, R7.2
unnamed: C13.1, J1.1, J1.2, R8.2
unnamed: R9.1, U1.44
unnamed: C14.2, U1.7
unnamed: LED1.A, R10.2
PA10: R10.1, U1.31
RSTN: U1.19, U2.37
RXN: J1.R6, U2.5
RXP: J1.R3, U2.6
S$1: R4.2, U1.9, U1.48, U4.8
SCLK: IC1.5, U1.26, U2.33
SCSN: U1.14, U2.32
TXN: J1.R2, U2.1
TXP: J1.R1, U2.2
